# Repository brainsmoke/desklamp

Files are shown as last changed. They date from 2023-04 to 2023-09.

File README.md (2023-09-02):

# desk lamp

An attempt to try to build something, mostly from materials I already had on hand.

White LED lamp made with aluminium PCBs

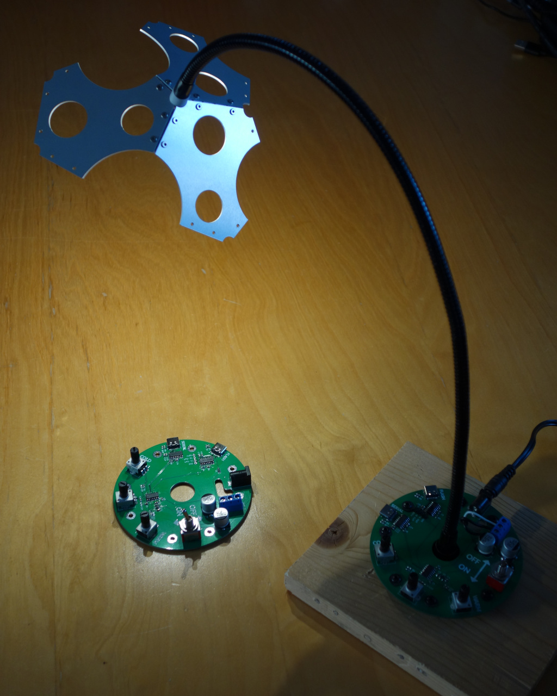
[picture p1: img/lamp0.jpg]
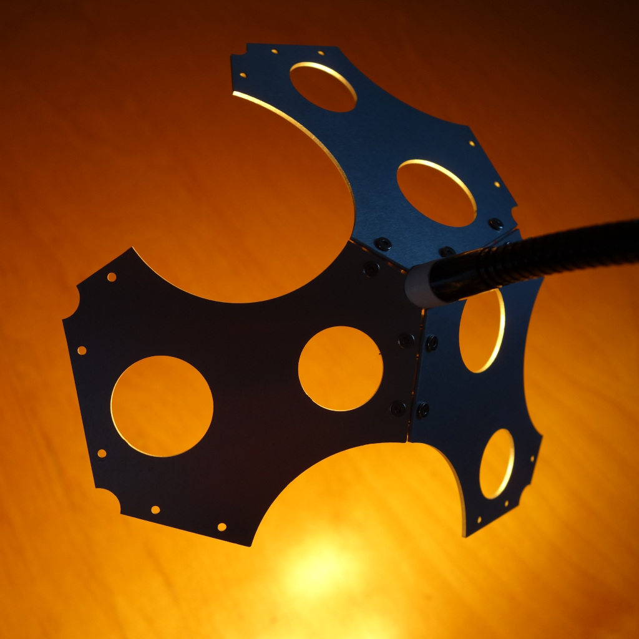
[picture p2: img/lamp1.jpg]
|  |  |
|-|-|
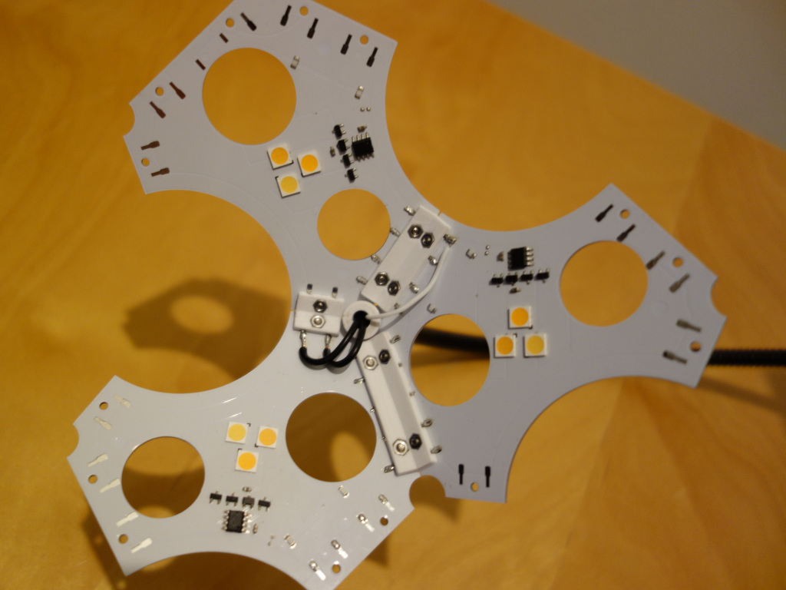
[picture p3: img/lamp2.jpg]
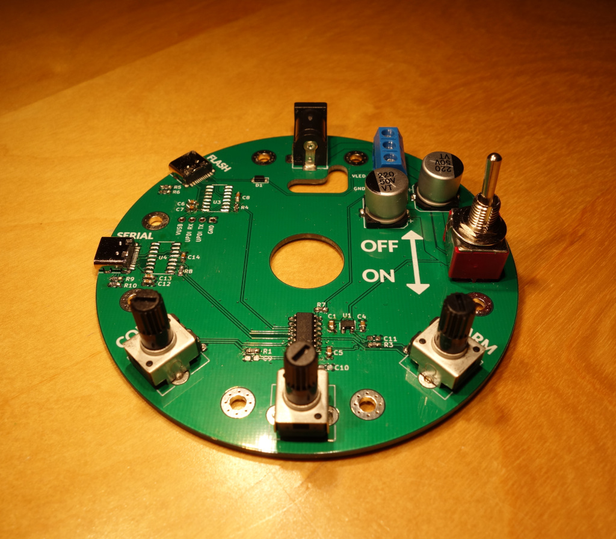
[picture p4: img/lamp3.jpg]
|  |  |

# Serial commands (115200 baud)

```
$ screen /dev/ttyUSB1 115200

lampsh> help
commands:

blink
debug
factory reset
help
load blink [fade {0.00-60.00}]
load calibrations
load custom {0..3} [fade {0.00-60.00}]
load default [fade {0.00-60.00}]
off [fade {0.00-60.00}]
on [fade {0.00-60.00}]
print
reset
restore blink
restore calibrations
restore custom {0..3}
restore default
save blink
save calibrations
save custom {0..3}
save default
set gamma {1.0-5.5}
set led {0..8} ({0.00-100.00} | dial{0,1,2}[:{0.00-100.00}]) [fade {0.00-60.00}]
set leds ({0.00-100.00} | dial{0,1,2}[:{0.00-100.00}]) x 9 [fade {0.00-60.00}]
set max brightness {0.00-100.00}

```

## examples

```
lampsh> set max brightness 50.00               # set maximum brightness to 50%
lampsh> save                                   # make it permanent by saving it to eeprom
```

```
lampsh> set led 2 dial2:50.00                  # use dial2 to dim led 2 in the range 0%-50%

lampsh> set leds dial0 0 0 0 dial1 0 0 0 dial2 # drive one led/dial, each a different temp & pcb

lampsh> set leds dial0 dial1 dial2 dial0 dial1 dial2 dial0 dial1 dial2 # default setting
```

# Firmware

```
apt install avr-gcc gmake pip3
pip3 install pymcuprog
cd firmware/attiny1624
make
make flash

```

# LED brightness calculation

```

    per LED                                      interpolate       apply     scale
     config                                      transition        gamma   brightness
 --------------                                 -------------     -------  ----------
                                                                              max 
 current config                                t_cur / interval    gamma   brightness
                                                     |               |         |
 .-------------.                                     V               V         |
 | per LED     |               .---.         .---------------.  .--------.     |
 | brightness  |---------------- * --------->|          .__  |  |        |     V
 |_____________|               '-^-'         |        ."     |  |       '|   .---.
                                 |           |       /       |->|      / |-->| * |
 .-------------.           .------------. .->|      /        |  |     /  |   '---'
 | per LED     |-dial 0-2->| dial value | |  |  __-'         |  | __-'   |     |
 | dial select |           |------------| |  '_______________'  '________'     |
 |_____________|-no dial-->| max        | |  |               |                 V
                           |____________| |  | sigmoid       |          .------------.
 previous config                          |  | interpolation |          |    LED     |
                                          |  |_______________|          | brightness |
 .-------------.                          |                             '------------'
 | per LED     |               .---.      |
 | brightness  |---------------- * -------'
 |_____________|               '-^-'
                                 |
 .-------------.           .------------.
 | per LED     |-dial 0-2->| dial value |
 | dial select |           |------------|
 |_____________|-no dial-->| max        |
                           |____________|
                           
```

# LED PCBs are leftovers from:

https://github.com/brainsmoke/aluball

## PADAUK software:

https://github.com/brainsmoke/softpwmpdk

`./write.sh <address>` for each in 0..2

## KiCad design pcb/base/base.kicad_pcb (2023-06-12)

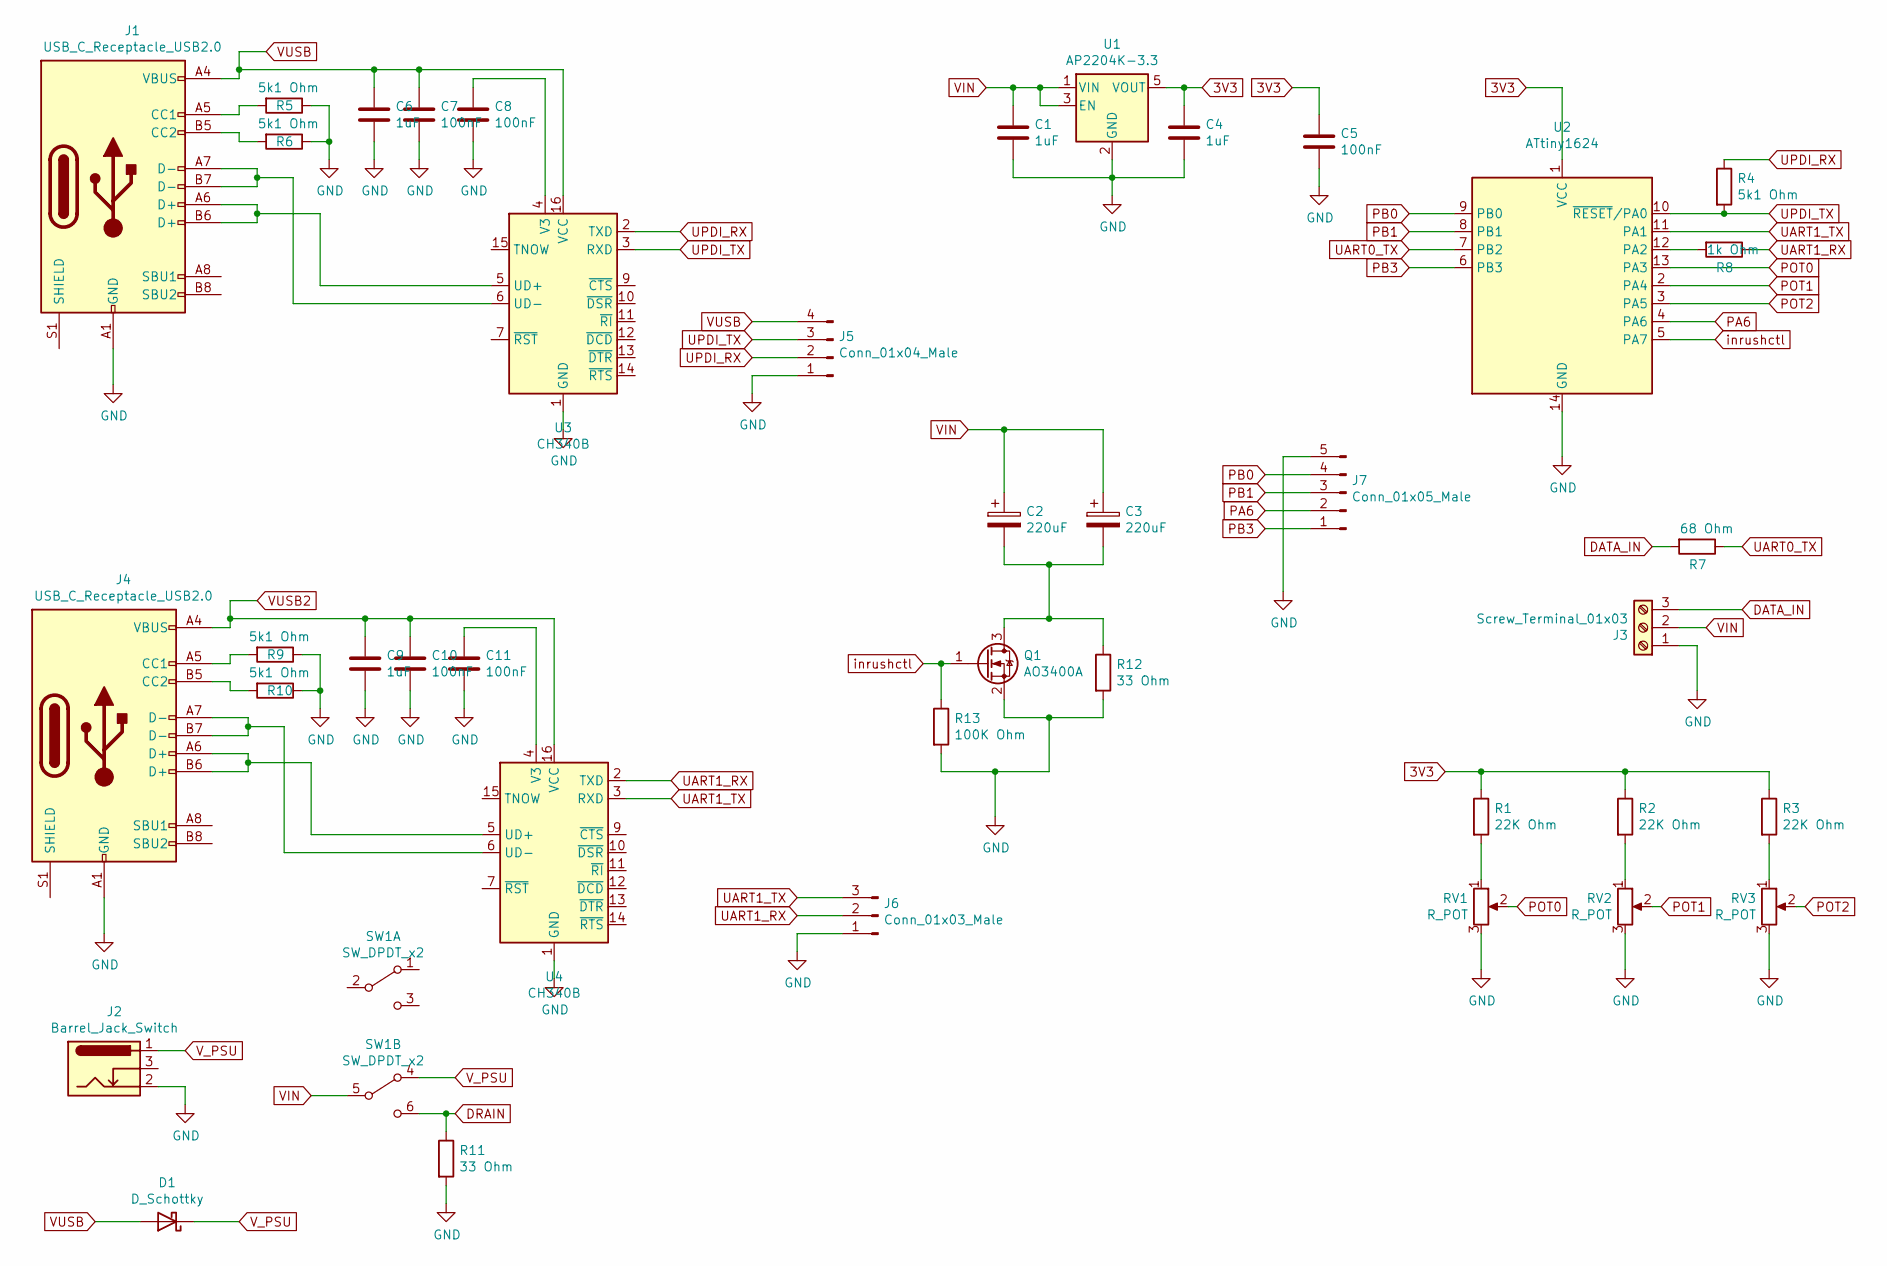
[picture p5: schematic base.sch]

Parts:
C1, C4, C6, C9: 1uF; C_0603_1608Metric_Pad1.08x0.95mm_HandSolder
C2, C3: 220uF; CP_Elec_10x10
C5, C7, C8, C10, C11: 100nF; C_0603_1608Metric_Pad1.08x0.95mm_HandSolder
D1: D_Schottky; D_SOD-123
J1, J4: USB_C_Receptacle_USB2.0; USB_C_Receptacle_HRO_TYPE-C-31-M-12
J2: Barrel_Jack_Switch; BarrelJack_Horizontal
J3: Screw_Terminal_01x03; TerminalBlock_Phoenix_PT-1,5-3-5.0-H_1x03_P5.00mm_Horizontal
J5: Conn_01x04_Male; PinHeader_1x04_P2.54mm_Vertical
J6: Conn_01x03_Male; PinHeader_1x03_P2.54mm_Vertical
J7: Conn_01x05_Male; PinHeader_1x05_P2.54mm_Vertical
Q1: AO3400A; SOT-23
R1, R2, R3: 22K Ohm; R_0603_1608Metric_Pad0.98x0.95mm_HandSolder
R4, R5, R6, R9, R10: 5k1 Ohm; R_0603_1608Metric_Pad0.98x0.95mm_HandSolder
R7: 68 Ohm; R_0603_1608Metric_Pad0.98x0.95mm_HandSolder
R8: 1k Ohm; R_0603_1608Metric_Pad0.98x0.95mm_HandSolder
R11, R12: 33 Ohm; R_1206_3216Metric_Pad1.30x1.75mm_HandSolder
R13: 100K Ohm; R_0603_1608Metric_Pad0.98x0.95mm_HandSolder
RV1, RV2, RV3: R_POT; Potentiometer_Alps_RK09L_Single_Vertical_radial
SW1: SW_DPDT_x2; MTS-20X_DPDT
U1: AP2204K-3.3; SOT-23-5
U2: ATtiny1624; SOIC-14_3.9x8.7mm_P1.27mm
U3, U4: CH340B; SOIC-16_3.9x9.9mm_P1.27mm

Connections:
3V3: C4.1, C5.1, R1.1, R2.1, R3.1, U1.5 (VOUT), U2.1 (VCC)
DATA_IN: J3.3, R7.2
DRAIN: R11.1, SW1.6 (C)
GND: C1.2, C4.2, C5.2, C6.2, C7.2, C8.2, C9.2, C10.2, C11.2, J1.A1 (GND), J1.A12 (GND), J1.B1 (GND), J1.B12 (GND), J2.2, J3.1, J4.A1 (GND), J4.A12 (GND), J4.B1 (GND), J4.B12 (GND), J5.1, J6.1, J7.5, Q1.2 (S), R5.1, R6.1, R9.1, R10.1, R11.2, R12.2, R13.2, RV1.3, RV2.3, RV3.3, U1.2 (GND), U2.14 (GND), U3.1 (GND), U4.1 (GND)
unnamed: C2.2, C3.2, Q1.3 (D), R12.1
unnamed: C8.1, U3.4 (V3)
unnamed: C11.1, U4.4 (V3)
unnamed: J1.A5 (CC1), R5.2
unnamed: J1.A6 (D+), J1.B6 (D+), U3.5 (UD+)
unnamed: J1.A7 (D-), J1.B7 (D-), U3.6 (UD-)
unnamed: J1.B5 (CC2), R6.2
unnamed: J4.A5 (CC1), R9.2
unnamed: J4.A6 (D+), J4.B6 (D+), U4.5 (UD+)
unnamed: J4.A7 (D-), J4.B7 (D-), U4.6 (UD-)
unnamed: J4.B5 (CC2), R10.2
unnamed: R1.2, RV1.1
unnamed: R2.2, RV2.1
unnamed: R3.2, RV3.1
unnamed: R8.2, U2.12 (PA2)
PA6: J7.2, U2.4 (PA6)
PB0: J7.4, U2.9 (PB0)
PB1: J7.3, U2.8 (PB1)
PB3: J7.1, U2.6 (PB3)
POT0: RV1.2, U2.13 (PA3)
POT1: RV2.2, U2.2 (PA4)
POT2: RV3.2, U2.3 (PA5)
UART0_TX: R7.1, U2.7 (PB2)
UART1_RX: J6.2, R8.1, U4.2 (TXD)
UART1_TX: J6.3, U2.11 (PA1), U4.3 (RXD)
UPDI_RX: J5.2, R4.1, U3.2 (TXD)
UPDI_TX: J5.3, R4.2, U2.10 (~RESET~/PA0), U3.3 (RXD)
VIN: C1.1, C2.1, C3.1, J3.2, SW1.5 (B), U1.1 (VIN), U1.3 (EN)
VUSB: C6.1, C7.1, D1.2 (A), J1.A4 (VBUS), J1.A9 (VBUS), J1.B4 (VBUS), J1.B9 (VBUS), J5.4, U3.16 (VCC)
VUSB2: C9.1, C10.1, J4.A4 (VBUS), J4.A9 (VBUS), J4.B4 (VBUS), J4.B9 (VBUS), U4.16 (VCC)
V_PSU: D1.1 (K), J2.1, SW1.4 (A)
inrushctl: Q1.1 (G), R13.1, U2.5 (PA7)

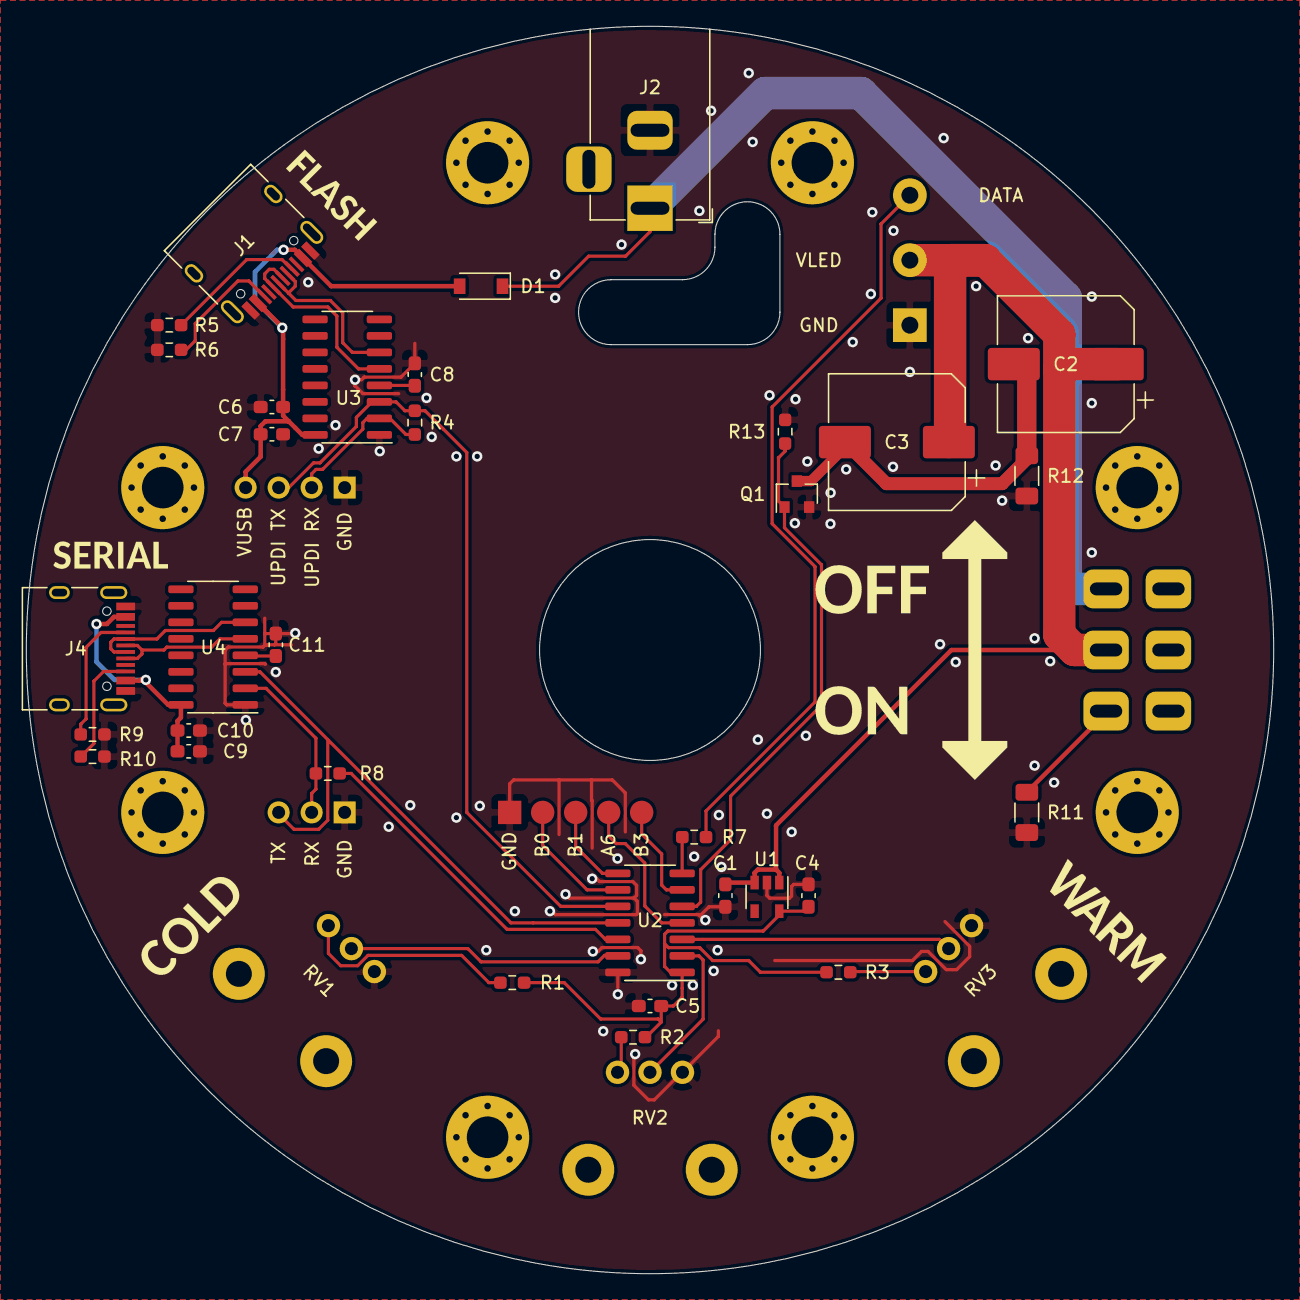
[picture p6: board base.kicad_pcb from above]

Board: 2 copper layers, 96.0 x 96.0 mm, 41 parts (0 on the bottom side), 36 nets.

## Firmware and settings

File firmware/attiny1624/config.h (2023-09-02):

#ifndef CONFIG_H
#define CONFIG_H

#define F_CPU 10000000UL
#define F_CPU_BITS (CLKCTRL_PEN_bm) /* has to match with the bits for F_CPU */

#define EEPROM_MAGIC (0x504d414c)

#define N_DIALS       3
#define DIAL_WHITE             0
#define DIAL_WARM_WHITE        1
#define DIAL_EXTRA_WARM_WHITE  2
#define NO_DIAL                3
#define STR_DIAL_RANGE        "dial{0,1,2}"


#define N_LEDS         9
#define STR_N_LEDS    "9"
#define STR_LED_RANGE "{0..8}"

#define STR_BRIGHTNESS_RANGE "{0.00-100.00}"

#define DEFAULT_FADE (60)
#define STR_FADE_RANGE "{0.00-60.00}"
#define FADE_MAX (6000)

#define STR_GAMMA_RANGE "{1.0-5.5}"

#define LED_ALL_OFF 0,0,0, 0,0,0, 0,0,0
#define LED_ALL_MAX 0xffff, 0xffff, 0xffff, 0xffff, 0xffff, 0xffff, 0xffff, 0xffff, 0xffff

#define LED_BLINK 0xffff, 0, 0, 0xffff, 0, 0, 0xffff, 0, 0

#define LED_ORDER DIAL_WHITE, DIAL_WARM_WHITE, DIAL_EXTRA_WARM_WHITE

#define LED_DIAL_MAP       LED_ORDER, LED_ORDER, LED_ORDER
#define LED_NO_DIAL_MAP NO_DIAL,NO_DIAL,NO_DIAL, NO_DIAL,NO_DIAL,NO_DIAL, NO_DIAL,NO_DIAL,NO_DIAL

#define LED_UART_RESHUFFLE 0,2,1,3,5,4,6,8,7

#define ANIMATION_QUEUE_SIZE 16

#define N_CUSTOM            4
#define N_PRESETS           6
#define PRESET_CUSTOM_BASE  0
#define PRESET_DEFAULT      4
#define PRESET_BLINK        5
#define STR_CUSTOM_RANGE "{0..3}"
#define PRESET_NAMES "custom 0", "custom 1", "custom 2", "custom 3", "default", "blink"

#define DIAL_MIN_DEFAULT 600
#define DIAL_MAX_DEFAULT 60000
#define DIAL_DEADZONE 400        /* full-on / full-off regions */

#define DEFAULT_MAX_BRIGHTNESS (65535)
#define DEFAULT_GAMMA_DEC (20) /* gamma = gamma_dec/10 */

#define ADC_PIN_0     3
#define ADC_PORT_0    PORTA
#define ADC_PINCTRL_0 PORTA.PIN3CTRL
#define ADC_AIN_0     3

#define ADC_PIN_1     4
#define ADC_PORT_1    PORTA
#define ADC_PINCTRL_1 PORTA.PIN4CTRL
#define ADC_AIN_1     4

#define ADC_PIN_2     5
#define ADC_PORT_2    PORTA
#define ADC_PINCTRL_2 PORTA.PIN5CTRL
#define ADC_AIN_2     5

#define USART0_BAUDRATE 38400
#define USART1_BAUDRATE 115200

#define USART0_RX_BUF_SZ (1)
#define USART1_RX_BUF_SZ (254)


#define USART0_PORTMUX PORTMUX_USART0_DEFAULT_gc // RX = PB3, TX = PB2
#define USART0_BAUD_REG ( (F_CPU*64 + 8ul*USART0_BAUDRATE)/(16ul*USART0_BAUDRATE) )

#define USART1_PORTMUX PORTMUX_USART1_DEFAULT_gc // RX = PA2, TX = PA1
#define USART1_BAUD_REG ( (F_CPU*64 + 8ul*USART1_BAUDRATE)/(16ul*USART1_BAUDRATE) )

#define USART0_RX_PIN 3
#define USART0_RX_PORT PORTB
#define USART0_RX_PINCTRL PORTB.PIN3CTRL

#define USART0_TX_PIN 2
#define USART0_TX_PORT PORTB
#define USART0_TX_PINCTRL PORTB.PIN2CTRL

#define USART1_RX_PIN 2
#define USART1_RX_PORT PORTA
#define USART1_RX_PINCTRL PORTA.PIN2CTRL

#define USART1_TX_PIN 1
#define USART1_TX_PORT PORTA
#define USART1_TX_PINCTRL PORTA.PIN1CTRL

#endif //CONFIG_H

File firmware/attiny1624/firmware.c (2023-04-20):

#include "config.h"

#include <avr/io.h>
#include <avr/interrupt.h>

#include "uart.h"
#include "adc.h"
#include "dial.h"
#include "rtc.h"
#include "gamma.h"
#include "io.h"
#include "prot.h"
#include "ani.h"
#include "system.h"
#include "settings.h"

volatile uint8_t tick=0;

void save(void)
{
	write_max_brightness(gamma_get_max());
	write_gamma_dec(gamma_get());

	uint8_t i;
	for (i=0; i<N_DIALS; i++)
	{
		dial_limit_t lim;
		dial_get_limits(i, &lim);
		write_limits(i, &lim);
	}
}


void load(void)
{
	gamma_set_max(read_max_brightness());
	gamma_set(read_gamma_dec());

	uint8_t i;
	for (i=0; i<N_DIALS; i++)
	{
		dial_limit_t lim;
		read_limits(i, &lim);
		dial_set_limits(i, &lim);
	}
}

void restore(void)
{
	write_max_brightness(DEFAULT_MAX_BRIGHTNESS);
	write_gamma_dec(DEFAULT_GAMMA_DEC);

	dial_limit_t lim;
	lim.min = DIAL_MIN_DEFAULT+DIAL_DEADZONE;
	lim.max = DIAL_MAX_DEFAULT-DIAL_DEADZONE;

	uint8_t i;
	for (i=0; i<N_DIALS; i++)
		write_limits(i, &lim);
}


void factory_reset(void)
{
	write_magic(EEPROM_MAGIC);
	write_version(EEPROM_VERSION);
	restore();

	uint8_t i;
	for (i=0; i<N_PRESETS; i++)
		write_preset(i, &preset_restore[i]);

	flush();
	reset();
}

static void print_config(const char *name, ledconfig_t *c)
{
	print(name);
	println(": ");
	print_led_config (c);
	println ("");
	println ("");
}

void print_state(void)
{
	print ("max brightness: ");
	print_brightness(gamma_get_max());
	println("");

	print ("gamma: ");
	print_u32_fixed_point(gamma_get(), 1);
	println("");

	println ("");
	uint8_t i;
	for (i=0; i<N_DIALS; i++)
	{
		print ("dial");
		print_u32(i);
		print (": ");
		print_brightness(dial_get(i));
		println("");
	}
	println ("");

	ledconfig_t config;

	ani_get_frame_top(&config);
	print_config("current config", &config);

	const char *names[] = { PRESET_NAMES };
	for(i=0; i<N_PRESETS; i++)
	{
		read_preset(i, &config);
		print_config(names[i], &config);
	}
}


void debug_print(void)
{
	print ("max brightness: ");
	print_u16(gamma_get_max());
	println("");

	print ("gamma: ");
	print_u32_fixed_point(gamma_get(), 1);
	println("");

	println ("");
	println ("dials:");
	uint8_t i;
	for (i=0; i<N_DIALS; i++)
	{
		dial_limit_t lim;
		dial_get_limits(i, &lim);
		print ("dial ");
		print_u16(i);
		print (": min= ");
		print_u16(lim.min);
		print (" max= ");
		print_u16(lim.max);
		print (" cur= ");
		print_u16(dial_get(i));
		print (" raw= ");
		print_u16(dial_get_raw(i));
//		print (" inv= ");
//		print_u32(dial_get_inv(i));
		println("");
	}

	for (i=0; i<N_LEDS; i++)
	{
		print ("led ");
		print_u16(i);
		print (": ");
		print_u16(ani_get_led(i));
		println("");
	}

	settings_t s;
	debug_read_settings(&s);
	print_hexbytes((uint8_t *)&s, sizeof(s));
	println("");
}

void rtc_tick(void)
{
	tick = 1;
}

void yield(void)
{
	dial_poll();
	uart_rx_poll();
}

static const uint8_t led_uart_reshuffle[N_LEDS] = { LED_UART_RESHUFFLE };

int main(void)
{
	set_clock();
	settings_init();

	adc_init();
	dial_init();
	uart_init();

	load();

	ani_init();
	prot_init();

	sei();
	rtc_init();
	for (;;)
	{
		ani_next();

		while (!tick)
		{
			prot_poll();
			yield();
		}

		uint8_t i;
		for (i=0; i<N_LEDS; i++)
		{
			uint16_t v = gamma_translate(ani_get_led(led_uart_reshuffle[i]));
			yield();
			uart0_putchar(v&0xff);
			yield();
			uart0_putchar(v>>8);
		}

		tick=0;
	}
}

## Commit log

2023-04-08 pcb ok, code untested
    [base-B_Cu.gbr, base-B_Mask.gbr, base-B_SilkS.gbr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]
2023-04-09 fix dial to colour mapping
    [config.h, firmware.c]
2023-04-14 add PCB image
2023-04-15 add led preset config parser function
2023-04-15 allow setting leds over serial
2023-04-18 add drain resistor to pcb
    [base-B_Cu.gbr, base-B_Mask.gbr, base-B_SilkS.gbr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]
2023-04-19 add uart header
    [base-B_Cu.gbr, base-B_Mask.gbr, base-B_SilkS.gbr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]
2023-04-19 change {load,save} commands to {load,save,restore} calibrations
2023-04-20 add print command
2023-04-20 add print command to readme
2023-04-21 add drain resistor to the switch's off side
    [base-B_Cu.gbr, base-B_Mask.gbr, base-B_SilkS.gbr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]
2023-04-22 document led brightness calculation
2023-04-22 remove unused caps
    [base-B_Cu.gbr, base-B_Mask.gbr, base-B_SilkS.gbr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]
2023-04-28 inrush current limitter
    [base.kicad_pcb, base.sch]
2023-04-30 add SMD pads for unused pins because why not
    [base.kicad_pcb, base.sch]
2023-06-12 set brownout fuse
2023-06-12 update PCB
    [base.kicad_pcb]
2023-09-02 fix on/off commands... oopsie
    [prot.c]
